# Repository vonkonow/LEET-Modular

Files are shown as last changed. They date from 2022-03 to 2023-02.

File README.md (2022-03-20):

# LEET-Modular
This is the GitHub repository containing source code, schematic and 3D models for the LEET modular device: https://vonkonow.com/wordpress/leet-modular/

Description: LEET modular is a multifunctional Eurorack compatible module. It is versatile, easy to build, cheap and open source.

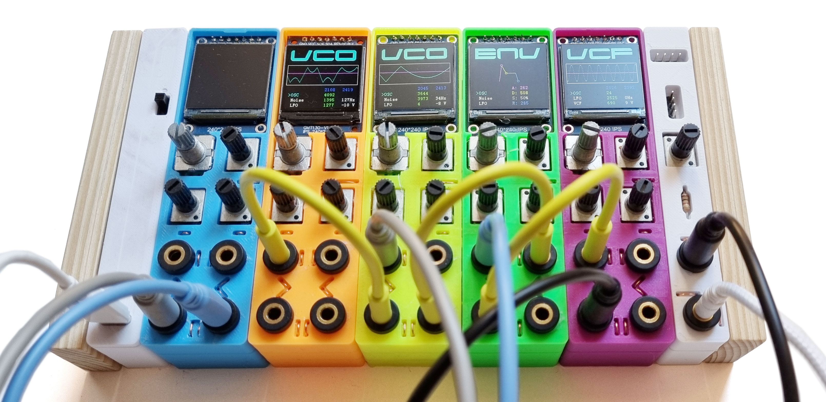
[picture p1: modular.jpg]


LEET modular offers a variety of different functions and by patching several units, advanced sounds and music can be generated.  

You can build your own device with a soldering iron and a handful of components. Everything is open source and hacking is encouraged!

Note that there are two versions:
1.	PCB version – where you can use the gerber files for a PCB order. Note that I have also designed optional 3D printed supports that protects the boards and allows units to be snapped together.
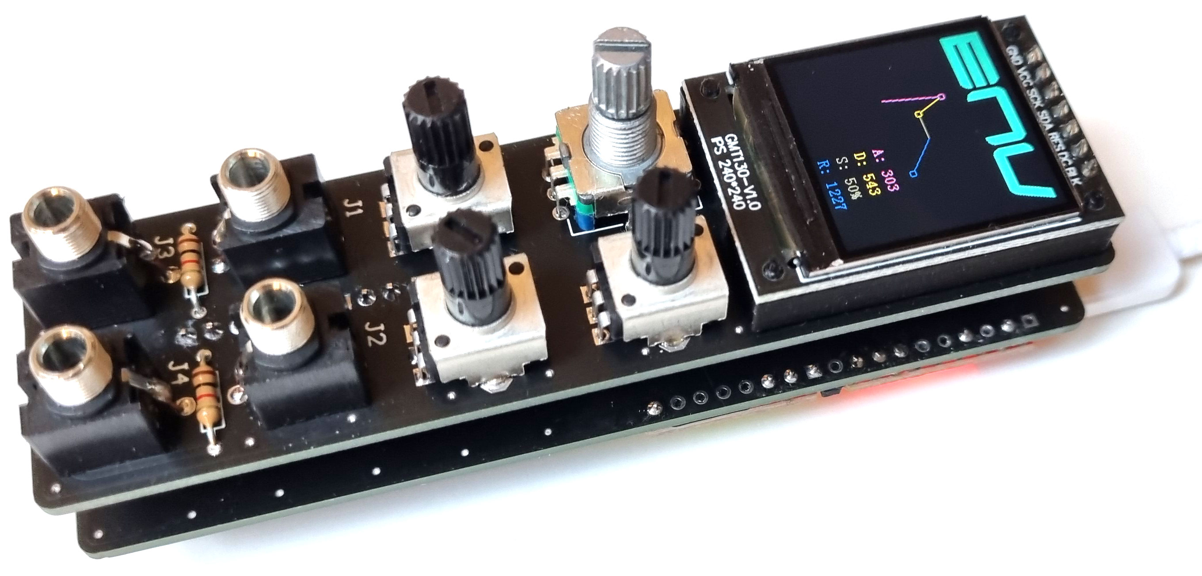
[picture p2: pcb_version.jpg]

2.	3DPCB version – where the 3D printed parts with copper wires replace the need for PCB order. The 3DPCB models is currently using single turn trimpots - making them challenging to tune. I have sketched on a multi turn version. Let me know if you are interested (so I get the motivation to update the model ;)

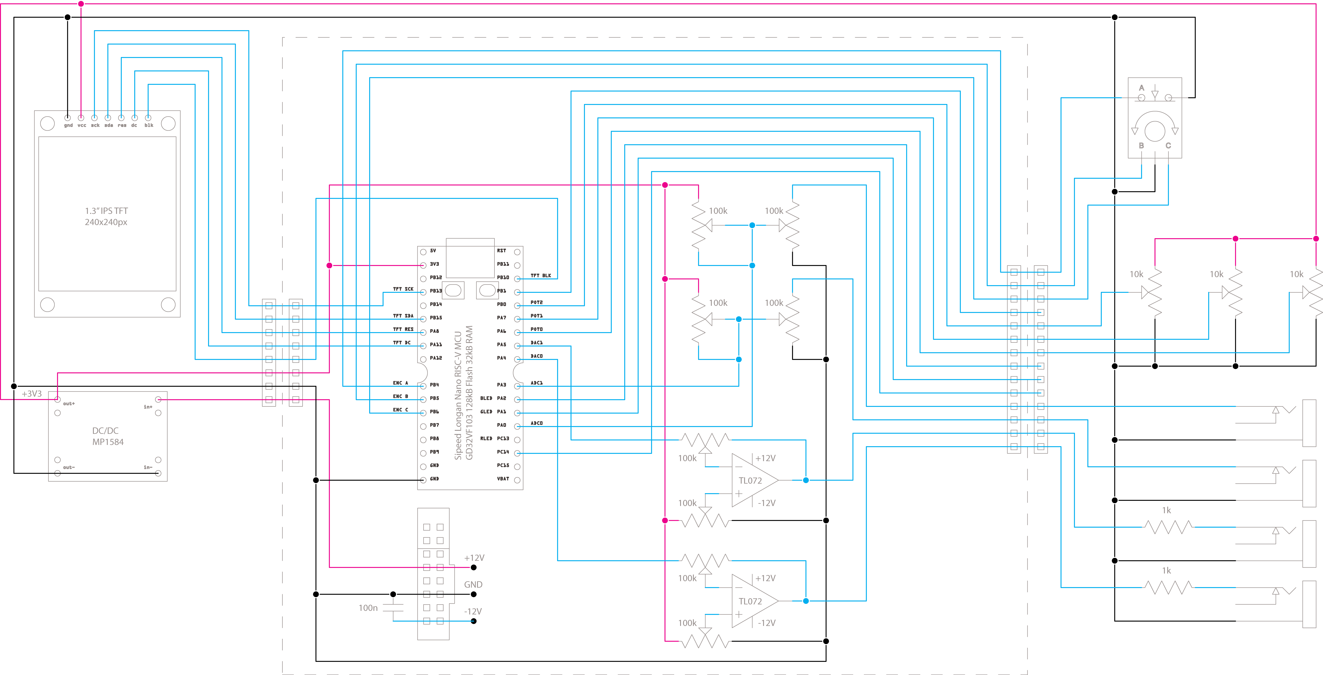
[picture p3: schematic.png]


Check out the forum where you can get support and contribute: https://vonkonow.com/wordpress/community/

For detailed building instructions visit: https://vonkonow.com/wordpress/leet-modular/

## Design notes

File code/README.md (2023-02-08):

This folder contains the platformIO src files for both the generic version (with VCO, LFO, ADSR etc.) and the midi2 cv version (using the USB C port as a midi device). 

The midi to CV codebase is based on https://github.com/nyannkov/nano_midi and is quite different than the generic version since it is relying on build scripts. It should be feasible to merge the two projects to a single project where the midi function is integrated in the menu system - let me know if you succeed ;)

The python scrips were used to generate icons, look up tables (LUT) and menus.

I used the following settings in platform.ini:
```
[env:sipeed-longan-nano]
platform = gd32v
board = sipeed-longan-nano
framework = gd32vf103-sdk
upload_protocol = dfu
```

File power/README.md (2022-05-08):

This folder contains 3d models for the USB-C powered Eurorack PSU. 

Check out the forum where you can get support and contribute: https://vonkonow.com/wordpress/community/

For detailed building instructions visit: https://vonkonow.com/wordpress/eurorack-psu/

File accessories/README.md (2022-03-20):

This folder contains 3d models for various accessories. 
Note that the caps for potentiometer and patch cables should be printed as spiral vase/shell - that means that the outer perimeter is printed in a continuous extrusion (single layer wall thickness). I used a prusa i3 mk3 with 0.4mm nozzle and PLA filament, the model or printer might need tuning to get good result...

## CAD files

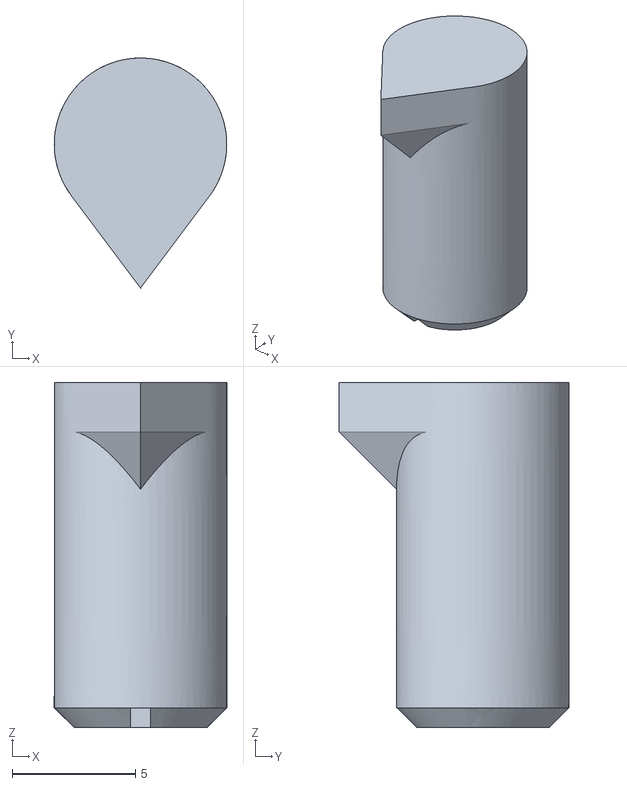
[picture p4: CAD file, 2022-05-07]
accessories/knob_pot.stl
7.00 x 9.33 x 14.0

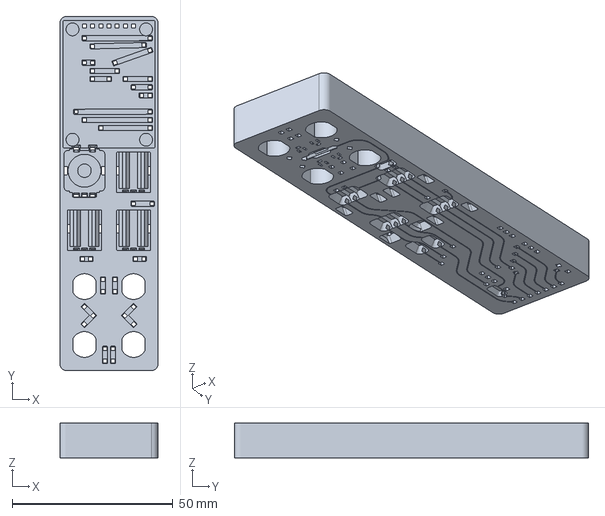
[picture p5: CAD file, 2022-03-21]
build_3dpcb/3dpcb_top.stp
30.5 x 110.0 x 10.8 mm

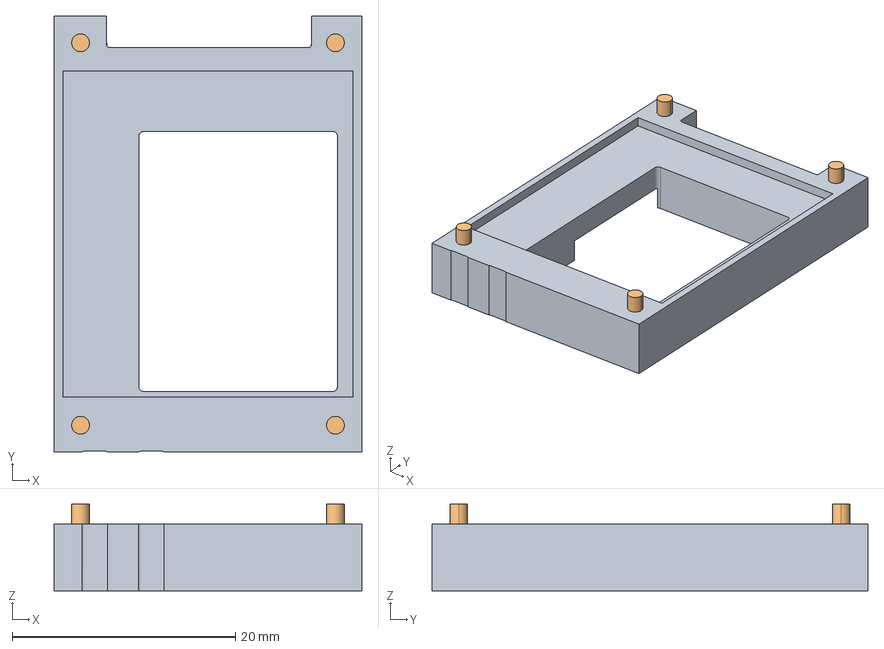
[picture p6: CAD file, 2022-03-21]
build_pcb/pcb_tft_support.stp
27.6 x 39.1 x 7.76 mm

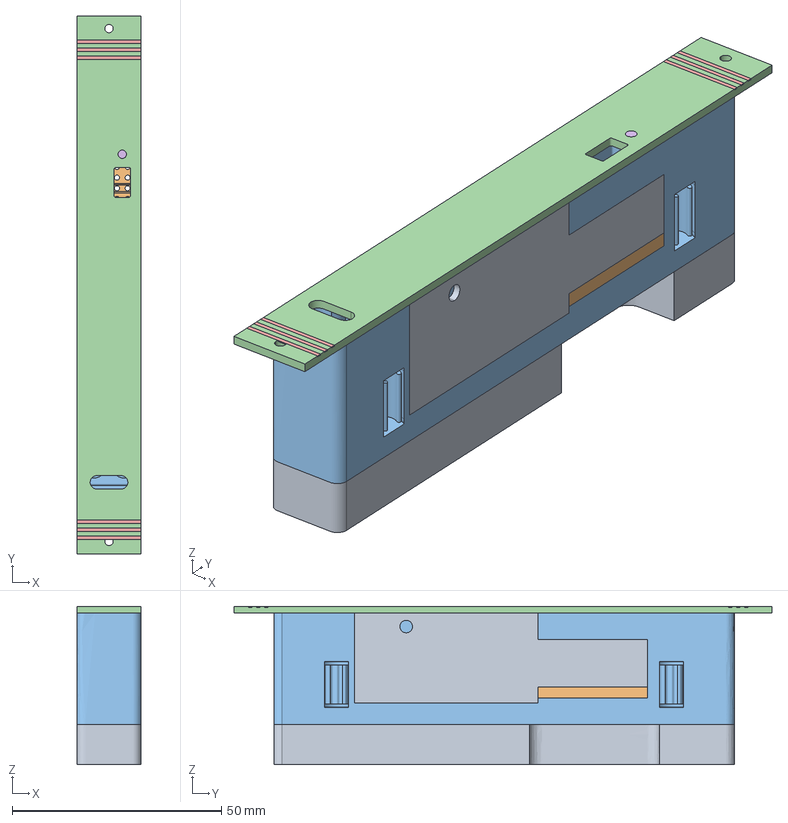
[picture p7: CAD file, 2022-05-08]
power/psu.stp
15.2 x 128.5 x 37.7 mm

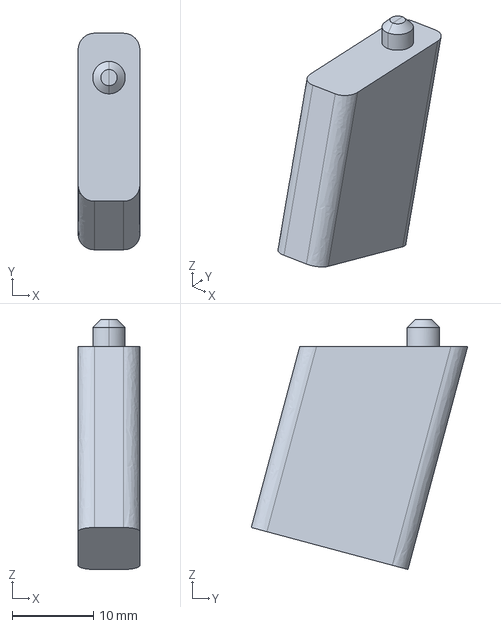
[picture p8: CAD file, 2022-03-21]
accessories/support15deg.stp
7.62 x 26.7 x 30.8 mm

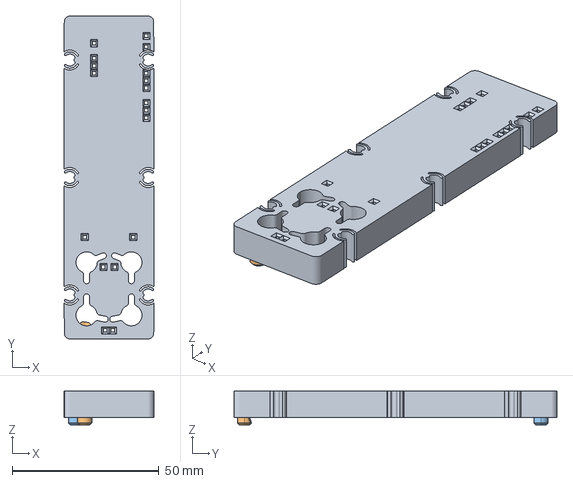
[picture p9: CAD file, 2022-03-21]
build_3dpcb/3dpcb_mid.stp
30.5 x 110.0 x 11.4 mm

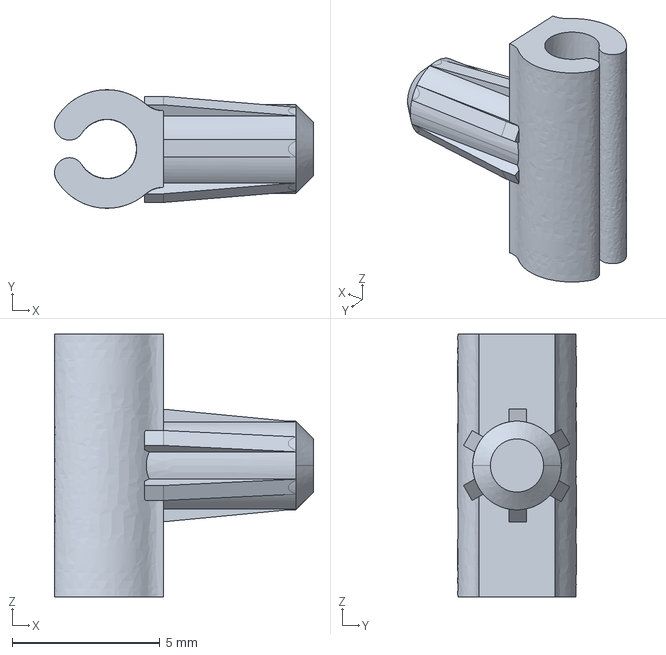
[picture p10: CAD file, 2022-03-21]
accessories/clip_wood.stp
8.76 x 4.01 x 8.89 mm

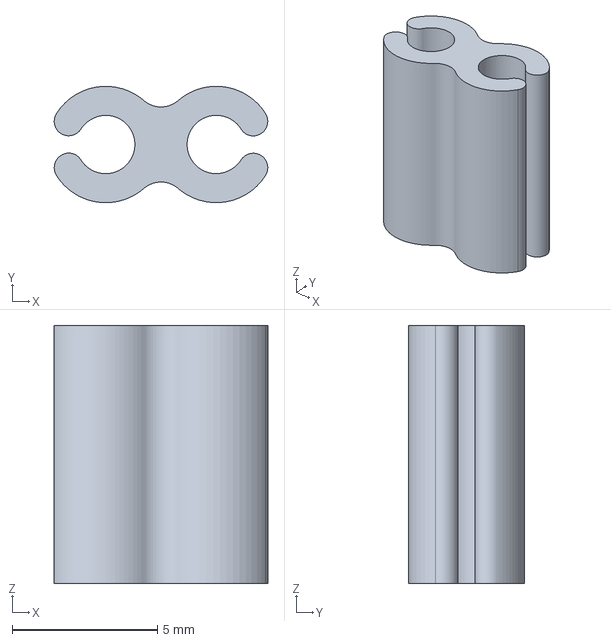
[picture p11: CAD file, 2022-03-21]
accessories/clip_clip.stp
7.36 x 4.01 x 8.89 mm

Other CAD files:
accessories/clip_clip.stl
accessories/clip_wood.stl
accessories/support15deg.stl
build_3dpcb/3dpcb_mid.stl
build_pcb/pcb_tft_support.stl

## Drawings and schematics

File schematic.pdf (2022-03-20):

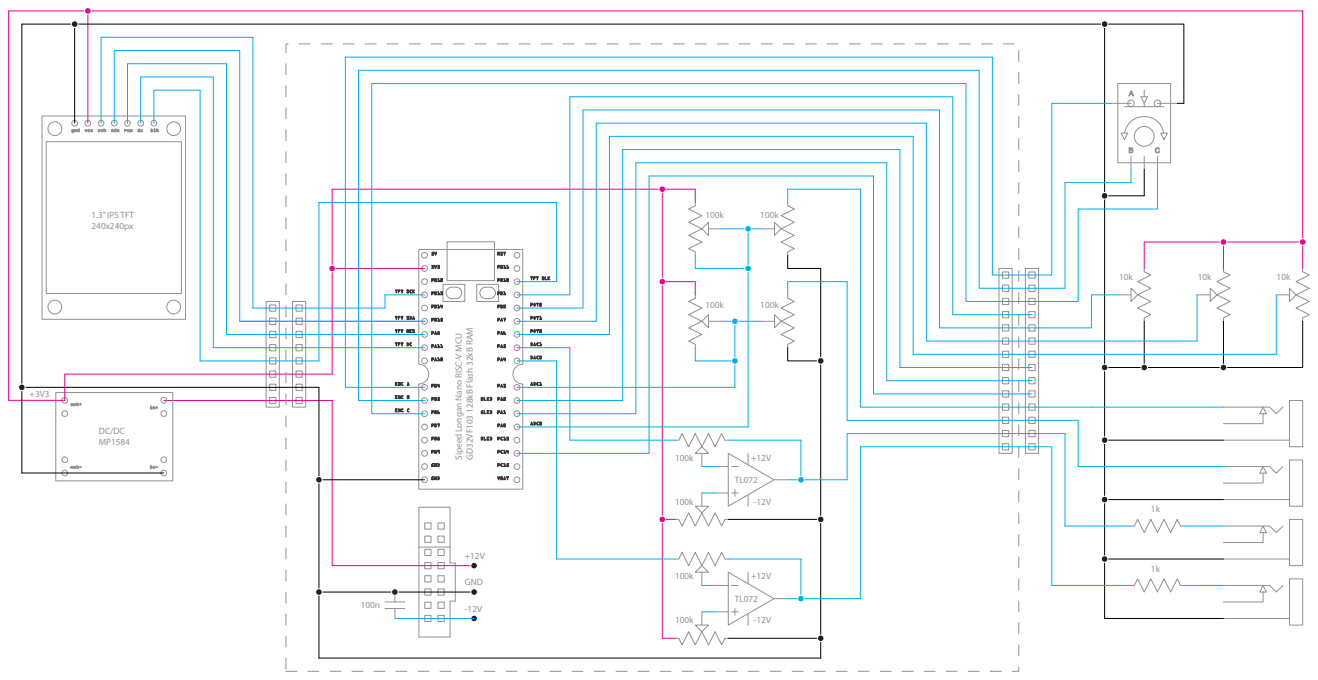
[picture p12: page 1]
GND; 1.3” IPS TFT 240x240px; GD32VF103 128kB Flash 32kB RAM

Sipeed Longan Nano RISC-V MCU

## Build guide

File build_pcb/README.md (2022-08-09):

This is the PCB version of LEET modular - upload the gerber file to the PCB manufacturer, while waiting for the order you can print the optional 3D parts that support the build, protects the components and have integrated snaps to attach modules together. 

There is a routing error in my PCB design, so three wires need to be adjusted in this version. I used the 3D printed adapter and copper wire instead of a pin header, allowing me to compensate for the error.
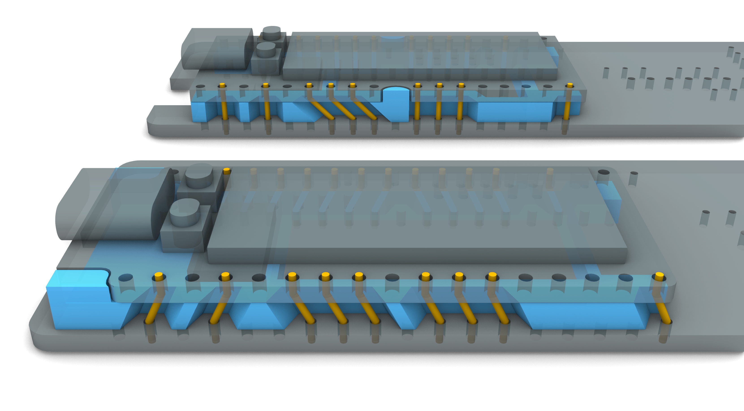
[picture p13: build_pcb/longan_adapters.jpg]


I have also included a 3D printed front panel as inspiration. The front panel can of course be replaced with a traditional aluminum panel, FR4/PCB or even a PCB with aluminum core...

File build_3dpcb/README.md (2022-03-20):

This is the 3DPCB version of LEET modular. 

This model has 3Dprinted parts with channels for copper wires replace the need for a PCB.
Note that this version is a bit trickier to assemble than the PCB version, especially since the final unit is difficult to correct once the wires from the different units are soldered together. Also note that this is an early version using single turn potentiometers making it difficult to tune with precision. I have sketched on a version with multi turn potentiometers, it will be slightly thicker like the PCB version. Let me know if this is of interest - it will hopefully encourage me to update the 3d model ;)

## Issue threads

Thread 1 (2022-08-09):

Pcb routing errors??

n9jcv, 2022-08-09:
Hello,

First let me say Thank You for all the hard work and sharing this great collection.

On your site I saw this comment;
"There is a routing error in my PCB design, so three wires need to be adjusted in the current version."

Can you tell me what the errors are so that I can fix them when I build or I can try to fix in the pcb.

Thanks

vonkonow, 2022-08-09:
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
here is a rendering of the adaptor I made to solve the routing error for longan nano 1.0 boards (back) and 1.1 boards (front)

n9jcv, 2022-08-09:
Is the schematic correcthere or on your site?

vonkonow, 2022-08-09:
The schematic is the same here and on the site, showing how the routing should be.
For example TFT_DC  shall go to PA11 (not to PA12 as in the gerber)

Closed 2023-02-20.

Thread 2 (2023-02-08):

Programming Help

ehisforadam, 2023-02-08:
I'm not really familiar with how programming works for this type of board. I have done Arduino, but I am a bit over my head here. I have seen examples for this board that include a platformio.ini file. Visuaual studio also doesn't seem to want to open or import the files off this Github page unless I rename main.cpp to main.ino, then I can import it as an Ardunino project. It seems to load everything, but when I got to compile it I get this error:
C:/Users/Adam/Documents/PlatformIO/Projects/230207-192426-sipeed-longan-nano/src/main.ino: In function 'void OnTimer()':
C:/Users/Adam/Documents/PlatformIO/Projects/230207-192426-sipeed-longan-nano/src/main.ino:589:17: error: request for member 'delay' in 'delay', which is of non-class type 'void(long unsigned int)'
  589 |     tmp = delay.delay(ADC.anRaw[0], ADC.anAvg[4], ADC.anAvg[3]); // sample, mix, length

vonkonow, 2023-02-08:
Hi
I used Platform IO in visual studio code. In theory it is possible to use Arduino IDE, but I haven’t tried, and I don’t know if programming would work. Unfortunately, It is a bit tricky to program the first time, hopefully it is better today, but I remember spending some time googling, downloading and installing different USB drivers...
Hope it helps, good luck!

ehisforadam, 2023-02-08:
Maybe I wasn't being clear. I am using Platformio and I was able to get examples and other code loaded onto the Longan board. The trouble I was having was getting the LEET modular code to be loaded correctly into Platformio. I was able to get Platformio to load it in by changing main to *.ino
I got that error within Platformio when compiling.

vonkonow, 2023-02-08:
I didnt use arduino as framework in platform io. Here is the ini file I used:
[env:sipeed-longan-nano]
platform = gd32v
board = sipeed-longan-nano
framework = gd32vf103-sdk
upload_protocol = dfu

ehisforadam, 2023-02-08:
Oh, I see, the platform in the ini file was messing things up. I am still getting a lot of errors when I try to compile it.
I put the ini file in the scr_generic folder with the scr folder. I was able to load it into Platformio, but I am still getting a bunch of errors when I try to compile it.

Verbose mode can be enabled via `-v, --verbose` option
CONFIGURATION: https://docs.platformio.org/page/boards/gd32v/sipeed-longan-nano.html
PLATFORM: GigaDevice GD32V (1.3.0) > Sipeed Longan Nano
HARDWARE: GD32VF103CBT6 108MHz, 32KB RAM, 128KB Flash
DEBUG: Current (altera-usb-blaster) External (altera-usb-blaster, gd-link, jlink, rv-link, sipeed-rv-debugger, um232h)
PACKAGES:
 - framework-gd32vf103-sdk @ 1.0.0
 - tool-dfuutil @ 1.9.200310
 - toolchain-gd32v @ 9.2.0
LDF: Library Dependency Finder -> https://bit.ly/configure-pio-ldf
LDF Modes: Finder ~ chain, Compatibility ~ soft
Found 0 compatible libraries
Scanning dependencies...
No dependencies
Building in release mode
Compiling .pio\build\sipeed-longan-nano\src\data\font.o
Compiling .pio\build\sipeed-longan-nano\src\data\frequency.o
Compiling .pio\build\sipeed-longan-nano\src\data\images.o
Compiling .pio\build\sipeed-longan-nano\src\drivers\SysTick.o
Compiling .pio\build\sipeed-longan-nano\src\drivers\adc.o
Compiling .pio\build\sipeed-longan-nano\src\drivers\display.o
Compiling .pio\build\sipeed-longan-nano\src\drivers\encoder.o
Compiling .pio\build\sipeed-longan-nano\src\drivers\scope.o
Compiling .pio\build\sipeed-longan-nano\src\drivers\spi.o
Compiling .pio\build\sipeed-longan-nano\src\drivers\timer.o
In file included from src\data\font.cpp:3:
C:\Users\Adam\.platformio\packages\framework-gd32vf103-sdk\GD32VF103_standard_peripheral/gd32vf103.h:179:41: error: redeclaration of C++ built-in type 'bool' [-fpermissive]
  179 | typedef enum {FALSE = 0, TRUE = !FALSE} bool;
      |                                         ^~~~
Compiling .pio\build\sipeed-longan-nano\src\drivers\usbfs\drv_usb_core.o
Compiling .pio\build\sipeed-longan-nano\src\drivers\usbfs\drv_usb_dev.o
In file included from src\data\frequency.cpp:3:
C:\Users\Adam\.platformio\packages\framework-gd32vf103-sdk\GD32VF103_standard_peripheral/gd32vf103.h:179:41: error: redeclaration of C++ built-in type 'bool' [-fpermissive]
  179 | typedef enum {FALSE = 0, TRUE = !FALSE} bool;
      |                                         ^~~~
In file included from src\data\images.cpp:3:
C:\Users\Adam\.platformio\packages\framework-gd32vf103-sdk\GD32VF103_standard_peripheral/gd32vf103.h:179:41: error: redeclaration of C++ built-in type 'bool' [-fpermissive]
  179 | typedef enum {FALSE = 0, TRUE = !FALSE} bool;
      |                                         ^~~~
In file included from src\drivers\SysTick.cpp:2:
C:\Users\Adam\.platformio\packages\framework-gd32vf103-sdk\GD32VF103_standard_peripheral/gd32vf103.h:179:41: error: redeclaration of C++ built-in type 'bool' [-fpermissive]
  179 | typedef enum {FALSE = 0, TRUE = !FALSE} bool;
      |                                         ^~~~
*** [.pio\build\sipeed-longan-nano\src\data\font.o] Error 1
In file included from src\drivers\adc.h:5,
                 from src\drivers\adc.cpp:1:
C:\Users\Adam\.platformio\packages\framework-gd32vf103-sdk\GD32VF103_standard_peripheral/gd32vf103.h:179:41: error: redeclaration of C++ built-in type 'bool' [-fpermissive]
  179 | typedef enum {FALSE = 0, TRUE = !FALSE} bool;
      |                                         ^~~~
*** [.pio\build\sipeed-longan-nano\src\drivers\SysTick.o] Error 1
*** [.pio\build\sipeed-longan-nano\src\data\images.o] Error 1
*** [.pio\build\sipeed-longan-nano\src\data\frequency.o] Error 1
In file included from src\drivers\encoder.cpp:3:
C:\Users\Adam\.platformio\packages\framework-gd32vf103-sdk\GD32VF103_standard_peripheral/gd32vf103.h:179:41: error: redeclaration of C++ built-in type 'bool' [-fpermissive]
  179 | typedef enum {FALSE = 0, TRUE = !FALSE} bool;
      |                                         ^~~~
*** [.pio\build\sipeed-longan-nano\src\drivers\adc.o] Error 1
In file included from src\drivers\display.cpp:7:
C:\Users\Adam\.platformio\packages\framework-gd32vf103-sdk\GD32VF103_standard_peripheral/gd32vf103.h:179:41: error: redeclaration of C++ built-in type 'bool' [-fpermissive]
  179 | typedef enum {FALSE = 0, TRUE = !FALSE} bool;
      |                                         ^~~~
In file included from src\drivers\timer.cpp:3:
C:\Users\Adam\.platformio\packages\framework-gd32vf103-sdk\GD32VF103_standard_peripheral/gd32vf103.h:179:41: error: redeclaration of C++ built-in type 'bool' [-fpermissive]
  179 | typedef enum {FALSE = 0, TRUE = !FALSE} bool;
      |                                         ^~~~
*** [.pio\build\sipeed-longan-nano\src\drivers\encoder.o] Error 1
src\drivers\usbfs\drv_usb_dev.c: In function 'usb_devcore_init':
src\drivers\usbfs\drv_usb_dev.c:80:17: warning: unused variable 'ram_addr' [-Wunused-variable]
   80 |     uint32_t i, ram_addr = 0;
      |                 ^~~~~~~~
src\drivers\usbfs\drv_usb_core.c: In function 'usb_txfifo_write':
src\drivers\usbfs\drv_usb_core.c:251:9: warning: 'packed' attribute ignored for type 'uint32_t *' {aka 'long unsigned int *'} [-Wattributes]
  251 |         *fifo = *((__packed uint32_t *)src_buf);
      |         ^
src\drivers\usbfs\drv_usb_core.c: In function 'usb_rxfifo_read':
src\drivers\usbfs\drv_usb_core.c:274:9: warning: 'packed' attribute ignored for type 'uint32_t *' {aka 'long unsigned int *'} [-Wattributes]
  274 |         *(__packed uint32_t *)dest_buf = *fifo;
      |         ^
In file included from src\drivers\spi.cpp:2:
C:\Users\Adam\.platformio\packages\framework-gd32vf103-sdk\GD32VF103_standard_peripheral/gd32vf103.h:179:41: error: redeclaration of C++ built-in type 'bool' [-fpermissive]
  179 | typedef enum {FALSE = 0, TRUE = !FALSE} bool;
      |                                         ^~~~
*** [.pio\build\sipeed-longan-nano\src\drivers\timer.o] Error 1
*** [.pio\build\sipeed-longan-nano\src\drivers\display.o] Error 1
*** [.pio\build\sipeed-longan-nano\src\drivers\spi.o] Error 1
========================================================== [FAILED] Took 1.29 seconds ==========================================================

ehisforadam, 2023-02-09:
This seems to be a topic related to this error I am getting, but I don't really know what it means: https://github.com/riscv-mcu/GD32VF103_Firmware_Library/pull/3

ehisforadam, 2023-02-09:
Oh hey, I think I got it to work. I had to replace the gd32vf103.h in the firmware folder and it compiled okay. Now to build the module up and see if she works.
File location: C:\Users\Adam\.platformio\packages\framework-gd32vf103-sdk\GD32VF103_standard_peripheral
New file: https://github.com/riscv-mcu/GD32VF103_Firmware_Library/blob/master/Firmware/GD32VF103_standard_peripheral/gd32vf103.h

ehisforadam, 2023-02-10:
Everything is together and working!

vonkonow, 2023-02-20:
Now that you mention it, I recall that I did the same procedure years ago. Strange that they still haven’t fixed it...
Anyway, glad that you got it working – well done :)

Closed 2023-02-10.

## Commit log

2022-03-20 Product photo - PCB version
    initial commit
2022-03-20 gerber file for PCB order
    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
2022-03-20 pdf (vector file) for print
    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
2022-03-20 schematic (bitmap)
    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
2022-03-20 Project description
    added schematic
2022-03-21 .STL Polygon mesh model for 3D printer
    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
2022-03-21 .STP NURBS model for editing in 3DCAD
    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
    [3dpcb_mid.stp]
2022-03-21 .STP NURBS model for editing in 3DCAD
    initital commit
    [support15deg.stp]
2022-05-07 .STL Polygon mesh model for 3D printer
    [knob_pot.stl]
2023-02-08 3D models for back cover (step & stl)
    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
2023-02-08 3D models for middle cover (step & stl)
    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
2023-02-08 3D models for thin front panel for LFO (stp & stl)
    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
